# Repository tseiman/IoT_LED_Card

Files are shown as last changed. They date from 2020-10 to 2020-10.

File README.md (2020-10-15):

# IoT LED Card

IoT card for Sierra Wireless MangOH (https://mangoh.io) boards and FX30 ready made IoT Device.
4 Controllable RGB LEDs. The RGB LEDs are driven via a 16 channel RGB controler PCA9685PW (https://www.nxp.com/docs/en/data-sheet/PCA9685.pdf). 
From this 16 channels 3 (RGB) x 4 LEDs = 12 Channels are used.
The IoT card uses the UART and a UART to I2C converter to communicate to the RGB controller.
UART to I2C conversion is done with SC18IM700 (https://www.nxp.com/docs/en/data-sheet/SC18IM700.pdf)

<p align="center">
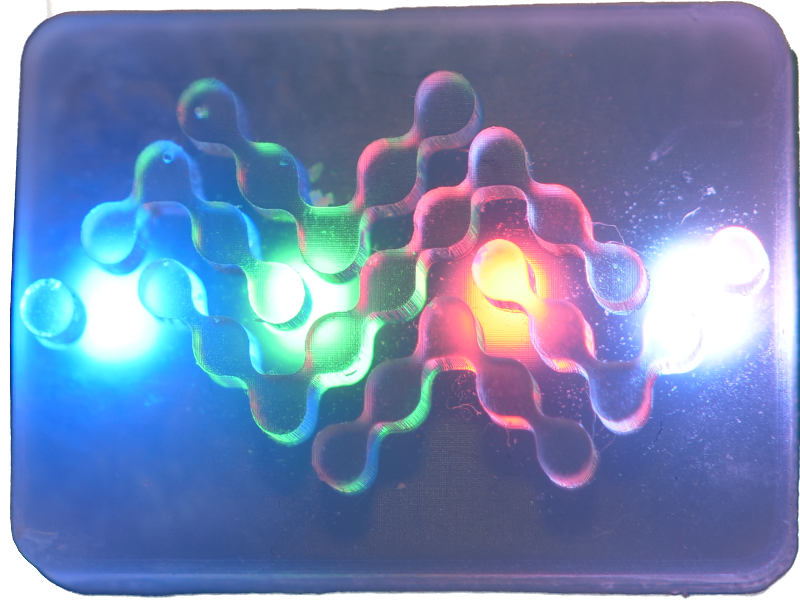
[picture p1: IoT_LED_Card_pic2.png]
	
</p>

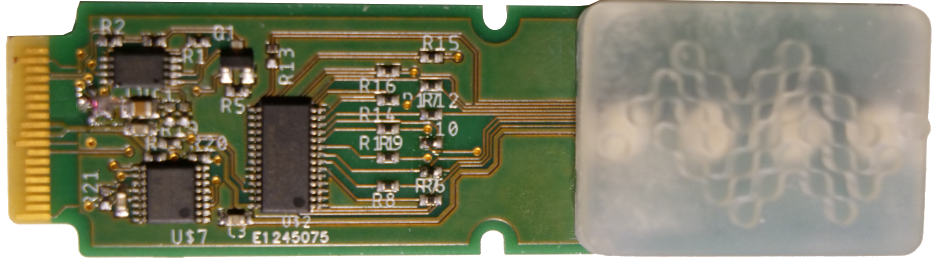
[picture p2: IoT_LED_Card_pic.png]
LED IoT Card


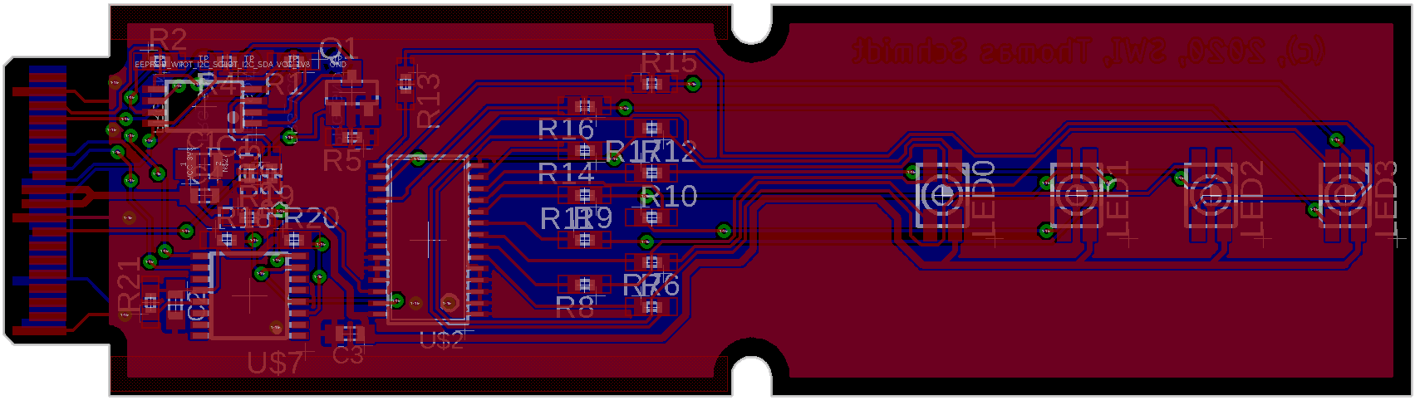
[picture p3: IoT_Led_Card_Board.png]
LED IoT Card


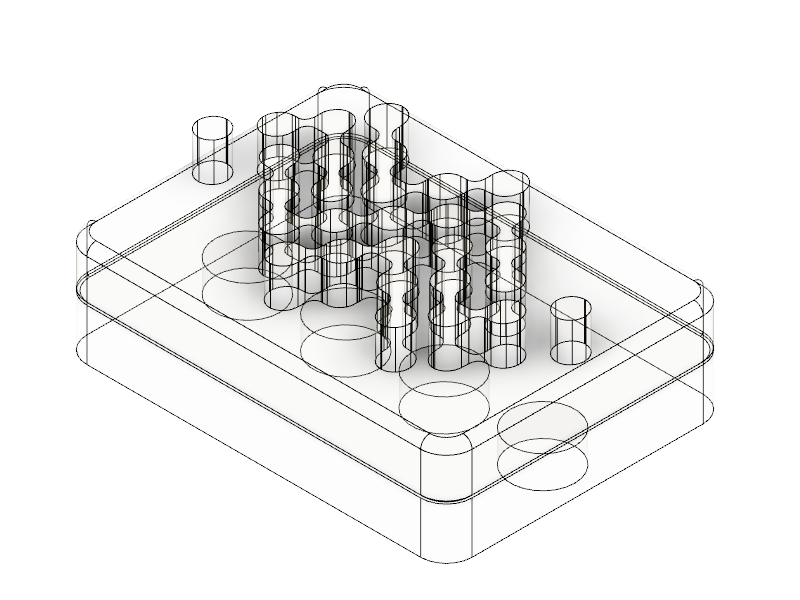
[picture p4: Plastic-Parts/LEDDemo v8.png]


## Communicating to I2C via the SC18IM700 converter
The address of the RGB driver PCA9685PW is fixed wired to 80h (write) and 81h (read).
The communication via UART is in binary. The UART itself runs in default mode of the SC18IM799 UART<-->I2C converter which is 9600Baud 8N1, no flow control.
For each I2C start command a 53h is send, for a I2C stop a 50h is send.
An example communication to write:
```
0x53 0x80 0x02 0xfa 0x00 0x50 

0x53 --> I2C Start Condition (executed by SC18IM700)
0x80 --> This is the I2C address of the I2C slave
0x02 --> 2 bytes to write (length)
0xfa 0x00 --> the data bytes
0x50 --> let the UART<-->I2C converter SC18IM700 create a I2C stop condition
```

Another Example:

```
// This sets the read pointer to the first register (Register MODE1) 
// of the RGB driver by writing 1 byte (0x01) with the value 0x0.
0x53 0x80 0x01 0x00 0x50

// This reads one byte from the RGB drivers's first register 
0x53 0x81 0x01 0x50
```
Please follow the datasheets of the RGB driver's PCA9685PW and the datasheet of the UART to I2C converter SC18IM700 tightly as the communication with this IoT Card is fully based on it. 

## Example Initialisation
The UART to I2C converter is running with it power up default settings. It is possible to set e.g. baud rate - which is not done at the moment (but everybody who implements a driver or an Octave script is free to do).
However the RGB needs to be initilized (the commands are all documented in the PCA9685 datasheet):

```
						// This both lines reset all LED channels:
0x53 0x80 0x02 0xfa 0x00 0x50     		// addresses register ALL_LED_ON_L (0xfa)
0x53 0x80 0x03 0xfc 0x10 0x00 0x50		// addresses register ALL_LED_OFF_L (0xfc) 
						
0x53 0x80 0x02 0x01 0x10 0x50			// addressing MODE2 register (0x01). 
						// Due to the design of the LED driver 
						// with the LEDs (LEDs are directly connected 
						// to the driver without FETs) 
						// the logic is inverted. This logic negation 
						// can be configured in MODE2 
						// register of RGB driver. For this setup 
						// INVRT bit must be HIGH and 
						// OUTDRV bit must be LOW - see the PCA9685 
						// Rev.4 datasheet p.29, Table 12. for
						// further information

0x53 0x80 0x01 0x00 0x50 0x53 0x81 0x01 0x50	// this reads the first (0x00) MODE1 
						// register by first setting the read 
						// pointer to first (0x00) register 
						// and then read 1 byte. It should 
						// return 0x11.
						// as autoincrement of the register 
						// is disabled by default on power up
						// we can directly write now to 
						// MODE1 register:
0x53 0x80 0x02 0x00 0x31 0x50			// the value 0x31 in MODE1 register
						// which disables RESTART and enables 
						// Register Auto Increment Please 
						// see PCA9685 Rev.4 datasheet p.14, 
						// Table 5. 
						// for further information, the PWM 
						// oscilator is still off at this stage

0x53 0x80 0x02 0xFE 0x79 0x50			// This set the PRE_SCALE Register (0xfe) 
						// to 50hz (can be adapted to different freq.)

0x53 0x80 0x02 0x00 0x21 0x50			// Changes in MODE1 register from Low power 
						// mode (Oscilators=Off) to normal mode (Osc.=On)

/* now PCA9685 needs 500us to stabilize the oscilator */
                                    
0x53 0x80 0x02 0x00 0xa1 0x50			// after 500us the initialisation 
						// can be finalized. After that 
						// we switch in MODE1 register the restart 
						// Bit (0xa1) - after restart the PCA9685 
						// is operational
    
```

## Writing to LED channels

The LED Driver offers 16 channels. Each Channel can be individually controlled with PWM parameters (related to one central Oscilator). 
The time of the duty cycle period and it's offset to the Oscilator clock can be defined by various registers.
Each channel has a LED_OFF_H, LED_OFF_L and a LED_ON_H, LED_ON_L register. The Low (L) registers are 8bit, from the High register only 4 Bits are used so in total a range of 0-4095 can be achived.
In this example the OFF registers are always on 0x0 (please check the PCA9685 datasheet for more in depth information). 

An example to set the brightnes of one channel:

```
53 80 03 06 00 00 50    53 80 03 08 ff 0f 50  	// The LED0 channel (first LED, Red) 
						// the LED_OFF Register is at address 0x06
//  LED0_OFF to 0x0	 LED0_ON to 4095 (max)	// the LED0 channel LED_ON Register is at 0x08
						// This sequence sets LED0 channel 
						// to maximum brightness.
						// Note that the LOW byte is transfered 
						// first - then the HIGH byte

```

## LED Channel Mapping:

| LED on IoT Card | Channel | Channel on PCA9685 | PCA9685 LED_OFF Addr. | PCA9685 LED_ON Addr. |
|:---:|:---:|:---:|:---:|:---:|
| 0		  | R	 | 0			 | 0x06			 | 0x08			|
| 0		  | G	 | 1			 | 0x0a			 | 0x0c			|
| 0		  | B	 | 2			 | 0x0e			 | 0x10			|
| 		  | 	 | 			 | 			 | 			|
| 1		  | R	 | 3			 | 0x12			 | 0x14			|
| 1		  | G	 | 4			 | 0x16			 | 0x18			|
| 1		  | B	 | 5			 | 0x1a			 | 0x1c			|
| 		  | 	 | 			 | 			 | 			|
| 2		  | R	 | 6			 | 0x1e			 | 0x20			|
| 2		  | G	 | 7			 | 0x22			 | 0x24			|
| 2		  | B	 | 8			 | 0x26			 | 0x28			|
| 		  | 	 | 			 | 			 | 			|
| 3		  | R	 | 9			 | 0x2a			 | 0x2c			|
| 3		  | G	 | 10		 | 0x2e			 | 0x30			|
| 3		  | B	 | 12		 | 0x32			 | 0x34			|

## Octave Example Code

### Initialisation 

Initialisation, Requires Counter Resource enabled, the Edge Action triggers on a Counter Observation 

```javascript
function(event) {

  if(event.value === 2) { // Huston we have a startup, triggering the first initialisation
    return {
      "dh://lcd/txt1": ["Init I2C"], 
      "vr://LED_I2C_is_init": [ false ], 
      "vr://ledI2CInitStep": [ 3 ], 
    }
  }

  var initDone = Datahub.read("/virtual/LED_I2C_is_init/value",0).value;

  if(initDone) {  // we're initialized don't do anything further
    return {"dh://lcd/txt1": ["no init"] }
  }
  var initStepValue = Datahub.read("/virtual/ledI2CInitStep/value",0).value; // if init is needed reading the counter value when init needs to be started

  var pca9685Init1 = { "data":  [
    0x53, 0x80, 0x02, 0xfa, 0x00, 0x50,
    0x53, 0x80, 0x03, 0xfc, 0x10, 0x00, 0x50,
    0x53, 0x80, 0x02, 0x01, 0x10, 0x50,
    0x53, 0x80, 0x01, 0x00, 0x50, 0x53, 0x81, 0x01, 0x50,
    0x53, 0x80, 0x02, 0x00, 0x31, 0x50,
    0x53, 0x80, 0x02, 0xFE, 0x79, 0x50,
    0x53, 0x80, 0x02, 0x00, 0x21, 0x50
  ]};

 var pca9685Init2 = { "data":  [
    0x53, 0x80, 0x02, 0x00, 0xa1, 0x50,
    0x53, 0x80, 0x03, 0x06, 0x00, 0x00, 0x50,    0x53, 0x80, 0x03, 0x08, 0x00, 0x00, 0x50,  
    0x53, 0x80, 0x03, 0x0a, 0x00, 0x00, 0x50,    0x53, 0x80, 0x03, 0x0c, 0x00, 0x00, 0x50,  
    0x53, 0x80, 0x03, 0x0e, 0x00, 0x00, 0x50,    0x53, 0x80, 0x03, 0x10, 0x00, 0x00, 0x50,  
  ]};

  if(event.value === initStepValue) { // Huston we have a startup, sending the first initialisation
    return {
      "dh://lcd/txt1": ["Running init seq"],                                                                              
      "dh://usp/write": [pca9685Init1],
    }

  }
  if(event.value === (initStepValue + 1)) { // actually we need to wait 500us until the PCM clock of the PCA9685 stabilizes - then we finalize, here we wait until the next couter incement (a bit longer than 500us) 
    return {
      "dh://lcd/txt1": ["DONE Running init seq"],                                                                              
      "dh://usp/write": [pca9685Init2],
      "vr://LED_I2C_is_init": [ true ], 
    }

  }
  
  return {  
     "dh://lcd/txt1": ["wait for init:" + event.value] 

  }

}

```

Writing brightness information:

```javascript
function(event) {

	if(event.value.type === "reset") {
      var initStepValue = Datahub.read("/util/counter/value",0).value + 1; 
		
      return {
        "dh://lcd/txt1": ["Init I2C"], 
        "vr://LED_I2C_is_init": [ false ], 
        "vr://ledI2CInitStep": [ initStepValue ], 
      }
  	}

	if(event.value.type === "setled") {

      var data = new Array();

	    if(event.value.hasOwnProperty("LED_0")){
	        var ledVal = event.value.LED_0;
	        if(ledVal.hasOwnProperty("R")){
	            var LEDvalue = ledVal.R;
	            var LED_Red_H = (LEDvalue & 0x0fff) >> 8;
	            var LED_Red_L = (LEDvalue & 0xff);
	            var ledCtrl = [0x53, 0x80, 0x03, 0x06, 0x00, 0x00, 0x50, 0x53, 0x80, 0x03, 0x08, LED_Red_L,   LED_Red_H,   0x50];
	            data.push.apply(data,ledCtrl);
	        }
	        if(ledVal.hasOwnProperty("G")){
	            var LEDvalue = ledVal.G;
	            var LED_Green_H = (LEDvalue & 0x0fff) >> 8;
	            var LED_Green_L = (LEDvalue & 0xff);
	        
	            var ledCtrl = [0x53, 0x80, 0x03, 0x0a, 0x00, 0x00, 0x50,    0x53, 0x80, 0x03, 0x0c, LED_Green_L, LED_Green_H, 0x50];
	            data.push.apply(data,ledCtrl);
	        }
	        if(ledVal.hasOwnProperty("B")){

	            var LEDvalue = ledVal.B;
	            var LED_Blue_H = (LEDvalue & 0x0fff) >> 8;
	            var LED_Blue_L = (LEDvalue & 0xff);
	        
	            var ledCtrl = [ 0x53, 0x80, 0x03, 0x0e, 0x00, 0x00, 0x50,    0x53, 0x80, 0x03, 0x10, LED_Blue_L,  LED_Blue_H,  0x50];
	            data.push.apply(data,ledCtrl);
	        }
	    }

	    if(event.value.hasOwnProperty("LED_1")){
	        var ledVal = event.value.LED_1;
	        if(ledVal.hasOwnProperty("R")){
	            var LEDvalue = ledVal.R;
	            var LED_Red_H = (LEDvalue & 0x0fff) >> 8;
	            var LED_Red_L = (LEDvalue & 0xff);
	            var ledCtrl = [0x53, 0x80, 0x03, 0x12, 0x00, 0x00, 0x50, 0x53, 0x80, 0x03, 0x14, LED_Red_L,   LED_Red_H,   0x50];
	            data.push.apply(data,ledCtrl);
	        }
	        if(ledVal.hasOwnProperty("G")){
	            var LEDvalue = ledVal.G;
	            var LED_Green_H = (LEDvalue & 0x0fff) >> 8;
	            var LED_Green_L = (LEDvalue & 0xff);
	        
	            var ledCtrl = [0x53, 0x80, 0x03, 0x16, 0x00, 0x00, 0x50,    0x53, 0x80, 0x03, 0x18, LED_Green_L, LED_Green_H, 0x50];
	            data.push.apply(data,ledCtrl);
	        }
	        if(ledVal.hasOwnProperty("B")){

	            var LEDvalue = ledVal.B;
	            var LED_Blue_H = (LEDvalue & 0x0fff) >> 8;
	            var LED_Blue_L = (LEDvalue & 0xff);
	        
	            var ledCtrl = [ 0x53, 0x80, 0x03, 0x1a, 0x00, 0x00, 0x50,    0x53, 0x80, 0x03, 0x1c, LED_Blue_L,  LED_Blue_H,  0x50];
	            data.push.apply(data,ledCtrl);
	        }
	    }

		if(event.value.hasOwnProperty("LED_2")){
			var ledVal = event.value.LED_2;
			if(ledVal.hasOwnProperty("R")){
			    var LEDvalue = ledVal.R;
			    var LED_Red_H = (LEDvalue & 0x0fff) >> 8;
			    var LED_Red_L = (LEDvalue & 0xff);
			    var ledCtrl = [0x53, 0x80, 0x03, 0x1e, 0x00, 0x00, 0x50, 0x53, 0x80, 0x03, 0x20, LED_Red_L,   LED_Red_H,   0x50];
			    data.push.apply(data,ledCtrl);
			}
			if(ledVal.hasOwnProperty("G")){
			    var LEDvalue = ledVal.G;
			    var LED_Green_H = (LEDvalue & 0x0fff) >> 8;
			    var LED_Green_L = (LEDvalue & 0xff);

			    var ledCtrl = [0x53, 0x80, 0x03, 0x22, 0x00, 0x00, 0x50,    0x53, 0x80, 0x03, 0x24, LED_Green_L, LED_Green_H, 0x50];
			    data.push.apply(data,ledCtrl);
			}
			if(ledVal.hasOwnProperty("B")){

			    var LEDvalue = ledVal.B;
			    var LED_Blue_H = (LEDvalue & 0x0fff) >> 8;
			    var LED_Blue_L = (LEDvalue & 0xff);

			    var ledCtrl = [ 0x53, 0x80, 0x03, 0x26, 0x00, 0x00, 0x50,    0x53, 0x80, 0x03, 0x28, LED_Blue_L,  LED_Blue_H,  0x50];
			    data.push.apply(data,ledCtrl);
			}
		}

		if(event.value.hasOwnProperty("LED_3")){
			var ledVal = event.value.LED_3;
			if(ledVal.hasOwnProperty("R")){
			    var LEDvalue = ledVal.R;
			    var LED_Red_H = (LEDvalue & 0x0fff) >> 8;
			    var LED_Red_L = (LEDvalue & 0xff);
			    var ledCtrl = [0x53, 0x80, 0x03, 0x2a, 0x00, 0x00, 0x50, 0x53, 0x80, 0x03, 0x2c, LED_Red_L,   LED_Red_H,   0x50];
			    data.push.apply(data,ledCtrl);
			}
			if(ledVal.hasOwnProperty("G")){
			    var LEDvalue = ledVal.G;
			    var LED_Green_H = (LEDvalue & 0x0fff) >> 8;
			    var LED_Green_L = (LEDvalue & 0xff);

			    var ledCtrl = [0x53, 0x80, 0x03, 0x2e, 0x00, 0x00, 0x50,    0x53, 0x80, 0x03, 0x30, LED_Green_L, LED_Green_H, 0x50];
			    data.push.apply(data,ledCtrl);
			}
			if(ledVal.hasOwnProperty("B")){

			    var LEDvalue = ledVal.B;
			    var LED_Blue_H = (LEDvalue & 0x0fff) >> 8;
			    var LED_Blue_L = (LEDvalue & 0xff);

			    var ledCtrl = [ 0x53, 0x80, 0x03, 0x32, 0x00, 0x00, 0x50,    0x53, 0x80, 0x03, 0x34, LED_Blue_L,  LED_Blue_H,  0x50];
			    data.push.apply(data,ledCtrl);
			}
		}

        if(data.length >= 14) {
          return {
            "dh://lcd/txt1": ["Write to LED " + data.length + " bytes"], 
            "dh://usp/write": [{ "data": data }],
          }
    	}

  	}

}

```

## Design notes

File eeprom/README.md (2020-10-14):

**eeprom_iot_LED_card.yaml** is a template file from which the IoT Card EEPROM image can be generated.

The image is only one time flashed to give the IoT Module it's identity and configuration parameters which might be read by a Legato Application or Kernel driver.

The yaml to EEPROM bin image conversion tool can be found from here:

https://github.com/mangOH/mangOH/tree/master/tools

The **writeFile2Eeprom** tool has to be cross compiled in a Legato legs environment and is meant to run directly on a WP module - in case the EEPROM is not flashed during production.

Clone and `make` Legato according to the advises from here: https://github.com/legatoproject/legato-af .

Run the Legato bin/legs environment. Change to this directory and check the Makefile. 
Adjust the Variables:

* $(WP77XX_SYSROOT)
* $(WP77XX_TOOLCHAIN_PREFIX)
* $(WP77XX_TOOLCHAIN_DIR)

At the moment it is set to be compiled for Sierra Wireless WP77XX modules. You might adjust it e.g. to
$(WP77XX_TOOLCHAIN_DIR) or similar for an other module series.

Compile the **writeFile2Eeprom** by `make` in this folder. 

Copy the compiled **writeFile2Eeprom** e.g. by `~> scp writeFile2Eeprom root@192.168.2.2:~`.

Insert a new, unflashed IoT card into the IoT slot of a MangOH board. 
Enable the EEPROM to write. For that the WP Signal of the EEPROM needs to be pulled down. On BX31 IoT Board hardware revision 1.0 the wire 
between R5 and the EEPROM has to be conencted to GND. On newer hardware revisions there is a testpoint which needs to be connected to GND.

Run **writeFile2Eeprom** with a correct set of parameters:

```
writeFile2Eeprom [-b <busID>] -f <eeprom image input file> [-y] -s <IoT card serial Number>
    -b <busID>                     optional,  the I2C bus ID - on MangOH red it is 5 (default)
    -f <eeprom image input file>   mandatory, the image which should be written to eeprom
    -y 	                           optional,  it will not ask if you are really sure
    -s <IoT Serial Number>         mandatory, a string with max 31 bytes with the serial information
                                   of the IoT card. BX31 IoT card SN should have following format:
                                   YYYYMMDDhhmmss_<HW Version>_<NumberInBatch> e.g.: 20201014123700_1.0_001
```

e.g.: `~> writeFile2Eeprom -b 5 -f eeprom_iot_LED_card.img -s 20201014123700_1.0_001`

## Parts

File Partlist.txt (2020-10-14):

Partlist

Exported from LED IoT Card.sch at 29.09.20 15:35

EAGLE Version 9.6.2 Copyright (c) 1988-2020 Autodesk, Inc.

Assembly variant: 

Part     Value                       Device           Package   Library                 Sheet

C1       1u                          C-EUC0805K       C0805K    rcl                     1
C2       100n                        C-EUC0603K       C0603K    rcl                     1
C3       100n                        C-EUC0603K       C0603K    rcl                     1
C4       100n                        C-EUC0603K       C0603K    rcl                     1
IC1      CAT24C32             YI-GT3 24C64ST          TSSOP8    microchip               1
LED0                                 0.13_RGB_LEDPLCC P-LCC-4-3 LEDs                    1
LED1                                 0.13_RGB_LEDPLCC P-LCC-4-3 LEDs                    1
LED2                                 0.13_RGB_LEDPLCC P-LCC-4-3 LEDs                    1
LED3                                 0.13_RGB_LEDPLCC P-LCC-4-3 LEDs                    1
Q1       BSS138                      BSS123           SOT23     transistor-small-signal 1

R1       10k                         R-EU_R0402       R0402     rcl                     1
R2       10k                         R-EU_R0402       R0402     rcl                     1
R3       10k                         R-EU_R0402       R0402     rcl                     1
R4       10k                         R-EU_R0402       R0402     rcl                     1
R5       10k                         R-EU_R0402       R0402     rcl                     1

R6       220                         R-EU_R0402       R0402     rcl                     1
R9       220                         R-EU_R0402       R0402     rcl                     1
R12      220                         R-EU_R0402       R0402     rcl                     1
R15      220                         R-EU_R0402       R0402     rcl                     1

R7       150                         R-EU_R0402       R0402     rcl                     1
R8       150                         R-EU_R0402       R0402     rcl                     1
R10      150                         R-EU_R0402       R0402     rcl                     1
R11      150                         R-EU_R0402       R0402     rcl                     1
R13      150                         R-EU_R0402       R0402     rcl                     1
R14      150                         R-EU_R0402       R0402     rcl                     1
R16      150                         R-EU_R0402       R0402     rcl                     1
R17      150                         R-EU_R0402       R0402     rcl                     1

R18      4k3                         R-EU_R0402       R0402     rcl                     1
R19      4k3                         R-EU_R0402       R0402     rcl                     1
R20      4k3                         R-EU_R0402       R0402     rcl                     1

R21      1k                          R-EU_R0402       R0402     rcl                     1

R22      100                         R-EU_R0402       R0402     rcl                     1

U$2      PCA9685PW                   PCA9685PW        TSSOP28   i2c-led-controller      1
U$7      SC18IM700IPWS8HP            SC18IM700IPWS8HP TSSOP16   SC18IM700IPW            1

-------------

1x           1u                          C-EUC0805K       C0805K    rcl                     1           	OK R - Conf
3x           100n                        C-EUC0603K       C0603K    rcl                     1 				OK R - Conf
4x		                                 0.13_RGB_LEDPLCC P-LCC-4-3 LEDs                    1       6x		OK R - Conf
1x 		     CAT24C32             YI-GT3 24C64ST          TSSOP8    microchip               1 				OK D - Conf
1x		     PCA9685PW                   PCA9685PW        TSSOP28   i2c-led-controller      1       4x		OK D - Conf
1x		     SC18IM700IPWS8HP            SC18IM700IPWS8HP TSSOP16   SC18IM700IPW            1       4x		OK D - Conf
1x			 BSS138                      BSS123           SOT23     transistor-small-signal 1 				OK D - Conf
5x 		     10k                         R-EU_R0402       R0402     rcl                     1    			OK R - Conf
4x		     220                         R-EU_R0402       R0402     rcl                     1   			OK R - Conf
8x       	 150                         R-EU_R0402       R0402     rcl                     1   			OK R - Conf
3x			 4k3                         R-EU_R0402       R0402     rcl                     1 				OK R - Conf
1x			 1k                          R-EU_R0402       R0402     rcl                     1 				OK R - Conf
1x			 100                         R-EU_R0402       R0402     rcl                     1 				OK R - Conf

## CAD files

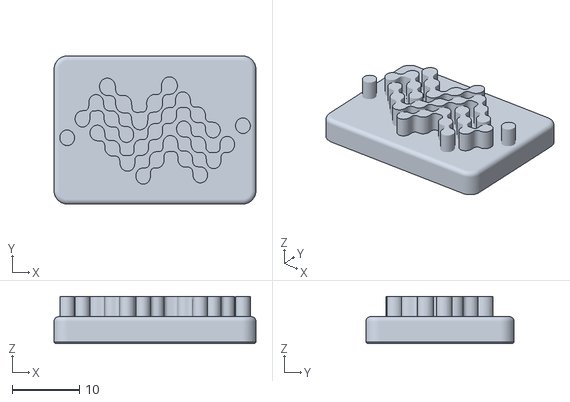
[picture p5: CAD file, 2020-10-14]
Plastic-Parts/LEDDemo v6.stl
30.0 x 22.0 x 7.00

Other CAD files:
Plastic-Parts/LEDDemov8.f3d

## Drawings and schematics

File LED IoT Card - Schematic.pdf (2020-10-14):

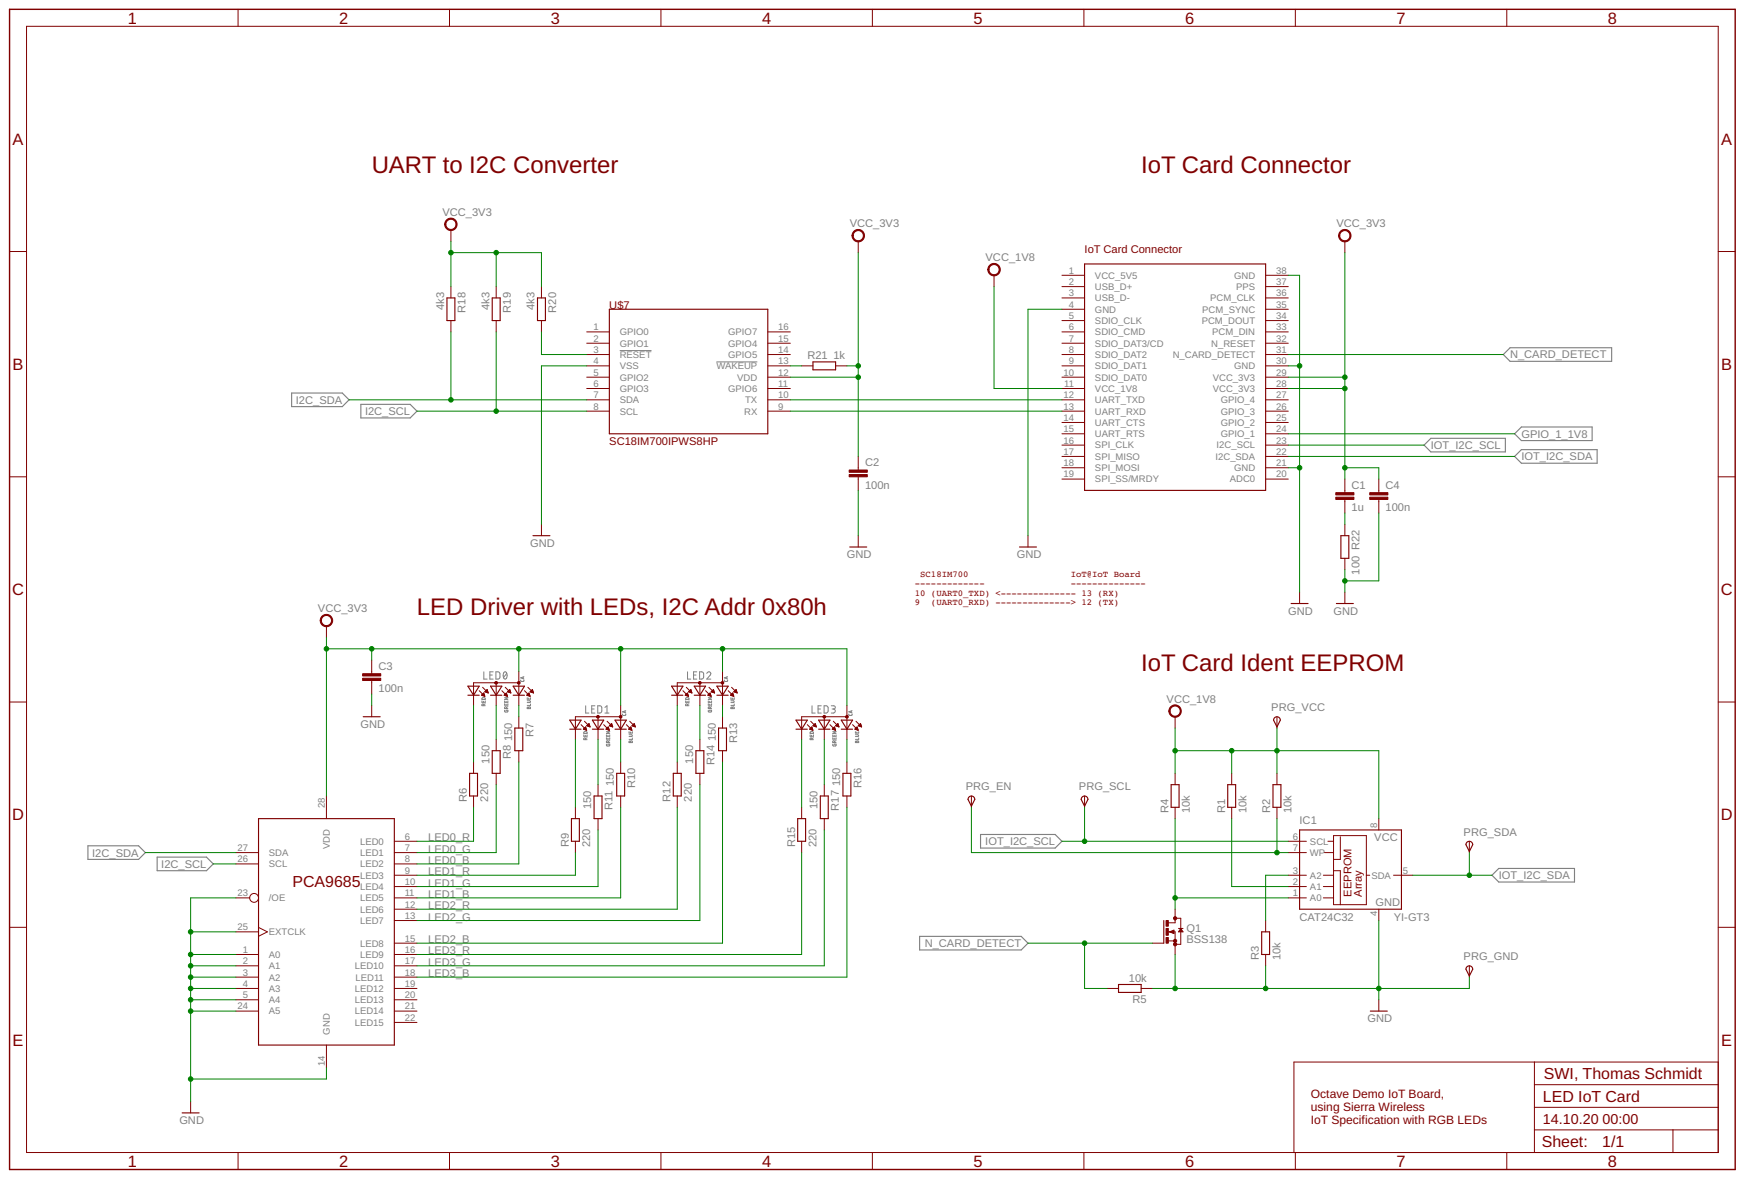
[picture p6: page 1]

IoT Card Ident EEPROM

Octave Demo IoT Board, using Sierra Wireless

IoT Specification with RGB LEDs

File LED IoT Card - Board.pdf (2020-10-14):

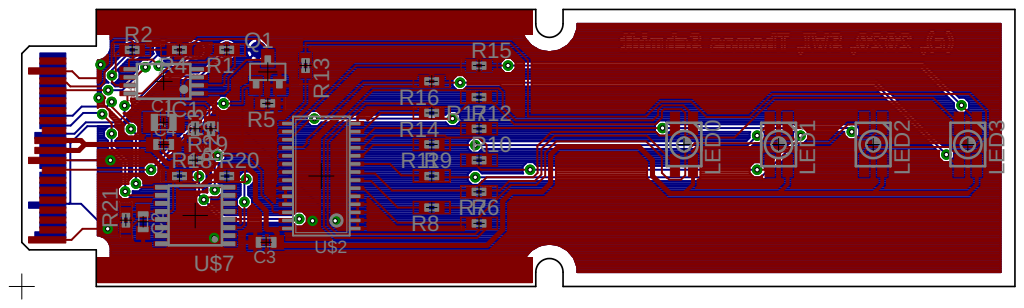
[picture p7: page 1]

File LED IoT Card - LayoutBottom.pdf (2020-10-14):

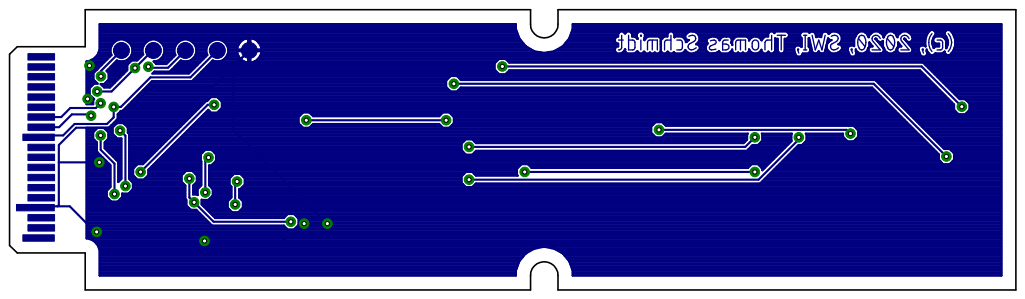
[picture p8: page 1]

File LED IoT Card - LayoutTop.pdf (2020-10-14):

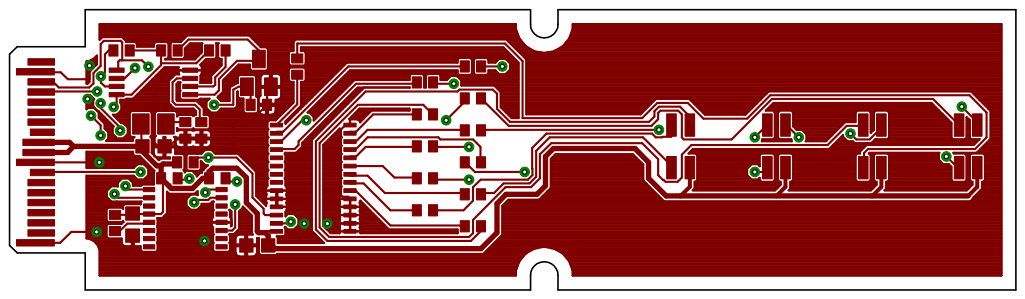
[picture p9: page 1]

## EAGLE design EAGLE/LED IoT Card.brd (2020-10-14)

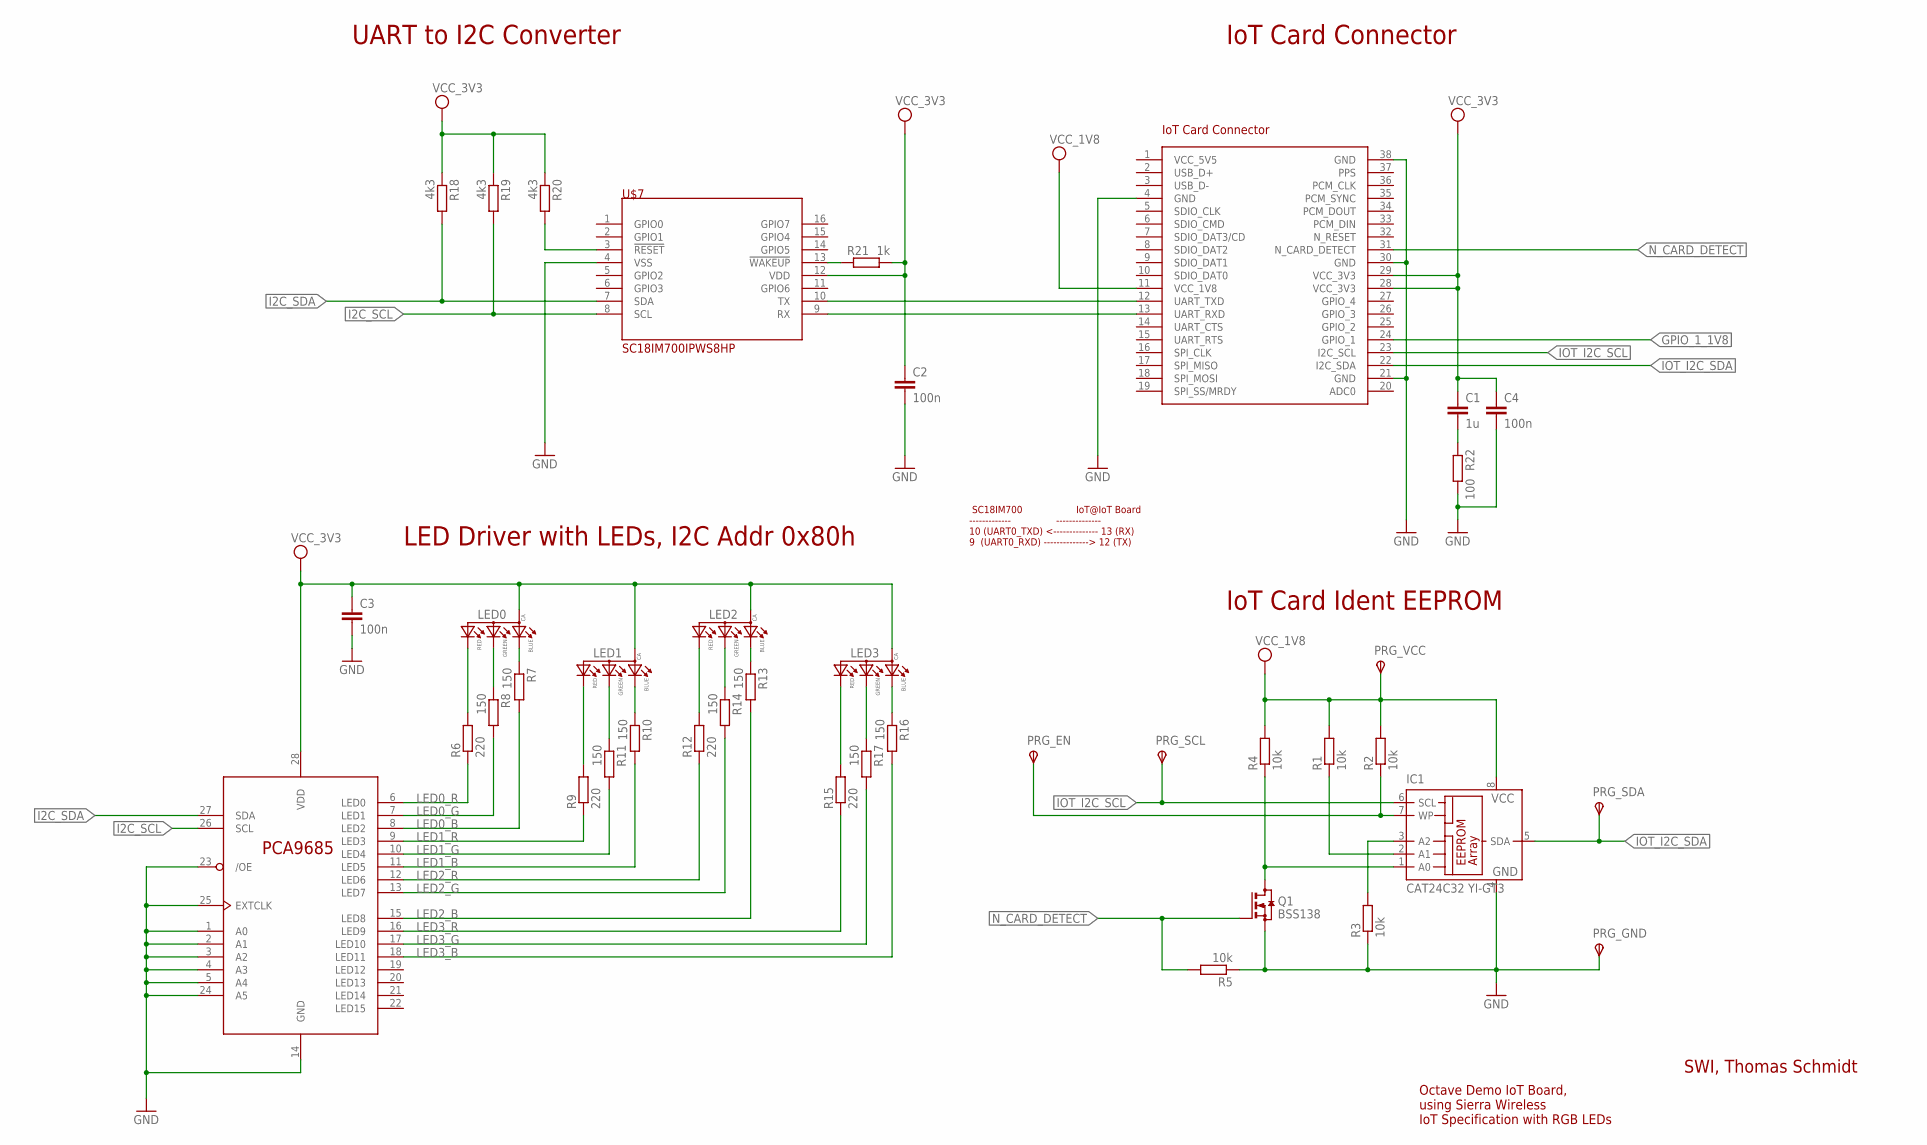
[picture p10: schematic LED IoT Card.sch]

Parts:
C1: 1u; C0805K
C2, C3, C4: 100n; C0603K
IC1: CAT24C32 YI-GT3; TSSOP8
LED0, LED1, LED2, LED3: 0.13_RGB_LEDPLCC; P-LCC-4-3
PRG_EN: TPSB1,27; B1,27
PRG_GND: TPSB1,27; B1,27
PRG_SCL: TPSB1,27; B1,27
PRG_SDA: TPSB1,27; B1,27
PRG_VCC: TPSB1,27; B1,27
Q1: BSS138; SOT23
R1, R2, R3, R4, R5: 10k; R0402
R6, R9, R12, R15: 220; R0402
R7, R8, R10, R11, R13, R14, R16, R17: 150; R0402
R18, R19, R20: 4k3; R0402
R21: 1k; R0402
R22: 100; R0402
U$1: IOTLONG; IOT_LONG
U$2: PCA9685PW; TSSOP28
U$7: SC18IM700IPWS8HP; TSSOP16

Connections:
EEPROM_A0: IC1.1 (A0), Q1.3 (D), R4.1
EEPROM_A1: IC1.2 (A1), R1.1
EEPROM_A2: IC1.3 (A2), R3.2
EEPROM_WP: IC1.7 (WP), PRG_EN.TP, R2.1
GND: C2.2, C3.2, C4.2, IC1.4 (GND), PRG_GND.TP, Q1.2 (S), R3.1, R5.1, R22.2, U$1.4 (GND), U$1.21 (GND), U$1.30 (GND), U$1.38 (GND), U$2.1 (A0), U$2.2 (A1), U$2.3 (A2), U$2.4 (A3), U$2.5 (A4), U$2.14 (GND), U$2.23 (/OE), U$2.24 (A5), U$2.25 (EXTCLK), U$7.4 (VSS)
GPIO_1_1V8: U$1.24 (GPIO_1)
I2C_SCL: R19.2, U$2.26 (SCL), U$7.8 (SCL)
I2C_SDA: R18.2, U$2.27 (SDA), U$7.7 (SDA)
IOT_I2C_SCL: IC1.6 (SCL), PRG_SCL.TP, U$1.23 (I2C_SCL)
IOT_I2C_SDA: IC1.5 (SDA), PRG_SDA.TP, U$1.22 (I2C_SDA)
LED0_B: R7.2, U$2.8 (LED2)
LED0_G: R8.2, U$2.7 (LED1)
LED0_R: R6.1, U$2.6 (LED0)
LED1_B: R10.2, U$2.11 (LED5)
LED1_G: R11.2, U$2.10 (LED4)
LED1_R: R9.1, U$2.9 (LED3)
LED2_B: R13.2, U$2.15 (LED8)
LED2_G: R14.2, U$2.13 (LED7)
LED2_R: R12.1, U$2.12 (LED6)
LED3_B: R16.2, U$2.18 (LED11)
LED3_G: R17.2, U$2.17 (LED10)
LED3_R: R15.1, U$2.16 (LED9)
unnamed: R20.2, U$7.3 (!RESET)
unnamed: R21.1, U$7.13 (!WAKEUP)
unnamed: C1.2, R22.1
N_CARD_DETECT: Q1.1 (G), R5.2, U$1.31 (N_CARD_DETECT)
RES_LED0_B: LED0.3 (BLUE), R7.1
RES_LED0_G: LED0.2 (GREEN), R8.1
RES_LED0_R: LED0.1 (RED), R6.2
RES_LED1_B: LED1.3 (BLUE), R10.1
RES_LED1_G: LED1.2 (GREEN), R11.1
RES_LED1_R: LED1.1 (RED), R9.2
RES_LED2_B: LED2.3 (BLUE), R13.1
RES_LED2_G: LED2.2 (GREEN), R14.1
RES_LED2_R: LED2.1 (RED), R12.2
RES_LED3_B: LED3.3 (BLUE), R16.1
RES_LED3_G: LED3.2 (GREEN), R17.1
RES_LED3_R: LED3.1 (RED), R15.2
SC18IM-RX_IOT-TX: U$1.12 (UART_TXD), U$7.10 (TX)
SC18IM-TX_IOT-RX: U$1.13 (UART_RXD), U$7.9 (RX)
VCC_1V8: IC1.8 (VCC), PRG_VCC.TP, R1.2, R2.2, R4.2, U$1.11 (VCC_1V8)
VCC_3V3: C1.1, C2.1, C3.1, C4.1, LED0.4 (ANODE), LED1.4 (ANODE), LED2.4 (ANODE), LED3.4 (ANODE), R18.1, R19.1, R20.1, R21.2, U$1.28 (VCC_3V3), U$1.29 (VCC_3V3), U$2.28 (VDD), U$7.12 (VDD)
VCC_5V5: U$1.1 (VCC_5V5)

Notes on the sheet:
IoT Card Ident EEPROM
SWI, Thomas Schmidt
Octave Demo IoT Board, using Sierra Wireless IoT Specification with RGB LEDs
SC18IM700 IoT@IoT Board ------------- -------------- 10 (UART0_TXD) <-------------- 13 (RX) 9 (UART0_RXD) --------------> 12 (TX)
LED Driver with LEDs, I2C Addr 0x80h
UART to I2C Converter
IoT Card Connector

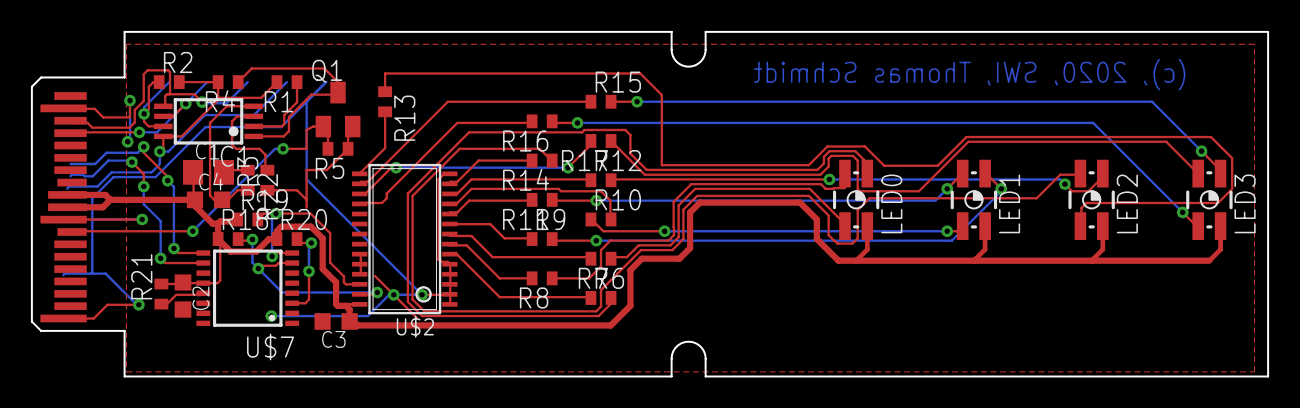
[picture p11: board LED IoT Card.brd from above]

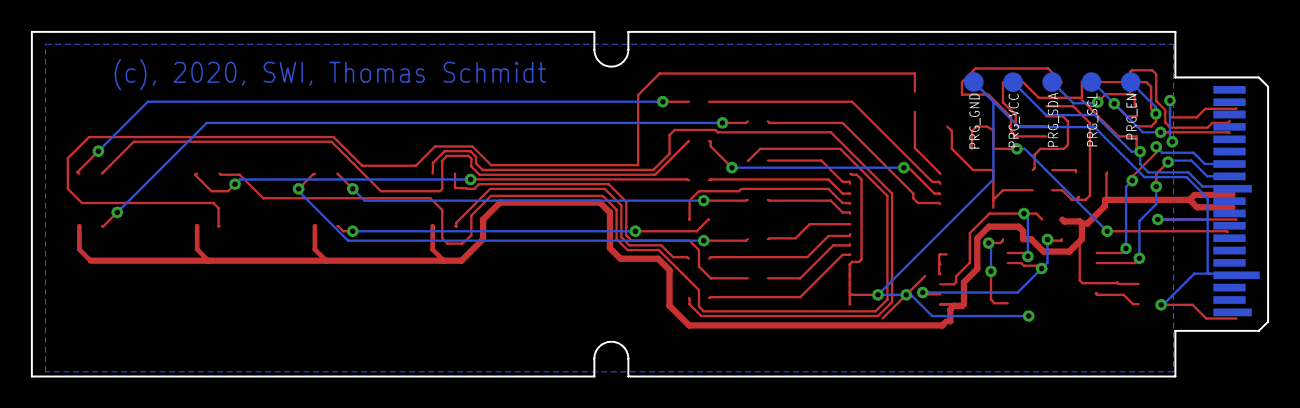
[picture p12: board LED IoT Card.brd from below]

Board: 2 copper layers, 80.0 x 22.3 mm, 40 parts (5 on the bottom side), 41 nets.

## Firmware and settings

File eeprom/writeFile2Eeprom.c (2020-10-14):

/**
 * by Thomas Schmidt Fr 09 Mai 2019 22:59:50 CEST
 * Tool to write the IoT EEPROM directly on an MangOH board.
 * EEPROM Write needs to be enabled (see IoT Board Readme and tool Readme)
 *
 **/


#include <unistd.h>
#include <stdio.h>
#include <stdlib.h>
#include <linux/i2c-dev.h>
#include <linux/limits.h>
#include <sys/ioctl.h>
#include <sys/types.h>
#include <sys/stat.h>
#include <fcntl.h>
#include <ctype.h>
#include <string.h>


#define DEFAULT_MANGOH_RED_IOT_I2C_BUS_ID	5
#define I2C_BASE_PATH				"/dev/i2c-"
#define MAX_SN_LEN 				32
#define EEPROM_SIZE				4096

#define SERIAL_NR_START_OFFSET			70
#define SERIAL_NR_STOP_OFFSET			101





int writeEeprom(char *fileName, char* deviceName, char *serialStr) {
    FILE *infile;
    unsigned char buffer[1] = "\0";
    int lenOfSnStr = strnlen(serialStr, MAX_SN_LEN);
    int snPos = 0;
    int device;
    unsigned char data[3];

    if ((infile = fopen(fileName, "rb")) < 0) {
	perror("ERROR: cannot open image file.");
	return 0;
    } 

    printf("\n");
    
    if ((device = open(deviceName, O_RDWR)) < 0) {
	perror("Can not open I2C Bus");
	return 200;
    }
    if (ioctl(device, I2C_SLAVE, 0x53) < 0) {
	perror("Can not connect to Device");
	return 201;
    }

    for(int i = 0; i < EEPROM_SIZE; ++i) {
	fread(&buffer, sizeof(unsigned char), 1, infile);
	if(i >= SERIAL_NR_START_OFFSET && i <= SERIAL_NR_STOP_OFFSET && snPos <= lenOfSnStr) {
	    buffer[0] = serialStr[snPos];
	    ++snPos;
	} 


	data[0]= (unsigned char) (i >> 8);	// High Byte Address
	data[1]= (unsigned char) i; 		// Low Byte Address
	data[2]= (unsigned char) buffer[0];	// Data Byte
	write(device,data,3);
	printf("\033[sWrite %d%% : addr %02x %02x , data= %x\033[u", i*100/EEPROM_SIZE+1, data[0], data[1], data[2]);
	usleep(5000);
    }
    printf("\n");

    close(device);
    fclose(infile);

    return 1;

} 


int checkEepromImgFileHeader(char *fileName) {
    FILE *fp;
    struct stat st;
    stat(fileName, &st);
    if(st.st_size != EEPROM_SIZE) return 0;
    unsigned char buffer[1] = "\0";

    if ((fp = fopen(fileName, "rb")) < 0) {
	perror("ERROR: cannot open image file.");
	return 0;
    } 
    fread(&buffer, sizeof(unsigned char), 1, fp);
    if(buffer[0] != 0xaa) return 0;

    fread(&buffer, sizeof(unsigned char), 1, fp);
    if(buffer[0] != 0x55) return 0;

    fclose(fp);
    return 1;
}



int main (int argc, char **argv) {

    char deviceName[PATH_MAX];
    char *inputFile = NULL;
    int busID = DEFAULT_MANGOH_RED_IOT_I2C_BUS_ID;
    int c;
    int noInteractive = 0;
    char securityQuestion;
    char serialString[MAX_SN_LEN];
    opterr = 0;

    memset(serialString,0,MAX_SN_LEN);

    while ((c = getopt (argc, argv, "b:f:s:hy")) != -1) {
	switch (c) {
    	    case 'b':
		for (int i=0;i< strlen(optarg); i++) {
    		    if (!isdigit(optarg[i])) {
        		printf ("ERROR: input for BusID is not a number\n");
        		return 1;
    		    }
		}
    		busID = atoi(optarg);
    		break;
    	    case 'f':
    		inputFile = optarg;
    		break;
    	    case 's':
    		if(strlen(optarg) > MAX_SN_LEN - 1) {
		    fprintf (stderr, "ERROR: serial number string too long - max len is %d - but actually given len is %d\n", MAX_SN_LEN -1 , (int)strlen(optarg));
		    return 1;
		}
		strncpy(serialString,optarg,MAX_SN_LEN -1);
    		break;
    	    case 'y':
    		noInteractive = 1;
    		break;
    	    case 'h':
    		printf("usage writeFile2Eeprom [-b <busID>] -f <eeprom image input file> [-y] -s <IoT card serial Number> \n");
    		printf("    -b <busID>                     optional,  the I2C bus ID - on MangOH red it is 5 (default)\n");
    		printf("    -f <eeprom image input file>   mandatory, the image which should be written to eeprom\n");
    		printf("    -y 	                           optional,  it will not ask if you are really sure\n");
    		printf("    -s <IoT Serial Number>         mandatory, a string with max 31 bytes with the serial information\n");
		printf("                                   of the IoT card. BX31 IoT card SN should have following format:\n");
		printf("                                   YYYYMMDDhhmmss_<HW Version>_<NumberInBatch> e.g.: 20190506200700_1.0_001\n");
		return 0;
    	    case '?':
    		if (optopt == 'f' || optopt == 'b') {
		    fprintf (stderr, "ERROR: Option -%c requires an argument.\n", optopt);
    		} else if (isprint (optopt)) {
        	    fprintf (stderr, "ERROR: Unknown option `-%c'.\n", optopt);
    		} else {
        	    fprintf (stderr, "ERROR: Unknown option character `\\x%x'.\n", optopt);
		}
		return 1;
    	    default:
    		abort ();
        }
    }

    if(access( inputFile , F_OK ) == -1 ) {
	fprintf(stderr,"Error: File %s - not found or readable.\n", inputFile);
	return 2;
    }

    if(strnlen(serialString,MAX_SN_LEN) < 1) {
	fprintf(stderr,"Error: Serial string %s - not correct.\n", serialString);
	return 4;

    }

    sprintf(deviceName, "%s%d", I2C_BASE_PATH, busID);

    if(! checkEepromImgFileHeader(inputFile)) {
	fprintf(stderr,"Error: File %s - doesn't seem to be a IoT card EEPROm image file.\n", inputFile);
	return 5;
    }

    printf("Please check carefully:\n");
    printf("  input file        =  %s\n", inputFile);
    printf("  I2C device Name   =  %s\n", deviceName);
    printf("  Device Serial ID  =  %s\n", serialString);
    
    if(!noInteractive) {
	do {
	    printf("Are you really sure to write to this device ? y/n: "); 
	    fflush(stdin);
    	    scanf(" %c",&securityQuestion);
	} while ( securityQuestion != 'n' && securityQuestion != 'y');
	if(securityQuestion == 'n') return 0; 
    }
    
    if(! writeEeprom(inputFile, deviceName, serialString)) { 
	fprintf(stderr,"Error: Failed to process image.\n");
	return 254;
    }

    printf("Successfuly wrote image.\n");
    
}

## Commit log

2020-10-14 initial commit with files
    [LED IoT Card.brd, LED IoT Card.sch, LEDDemo v6.stl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]
2020-10-14 updated the board image
2020-10-15 correctd board picture

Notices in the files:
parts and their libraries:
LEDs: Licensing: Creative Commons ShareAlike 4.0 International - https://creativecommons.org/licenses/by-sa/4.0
